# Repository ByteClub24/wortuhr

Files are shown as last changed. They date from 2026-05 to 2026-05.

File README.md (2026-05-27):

# Wortuhr

Open-Source-Wortuhr mit 10×10 LED-Raster — ein offenes Vereinsprojekt des [ByteClub](https://byteclub.at).

> Status: 🚧 in Entwicklung. CAD-Konstruktion läuft, Firmware folgt.

## Was ist das?

Eine Wortuhr zeigt die Uhrzeit in geschriebenen Worten an — bei dieser Variante mit österreichischen Dialekt-Begriffen wie *"HOIBE"*, *"OCHT"*, *"ZWO"*. Hinter einer Frontplatte sitzt ein 10×10-Raster aus einzeln ansteuerbaren NeoPixel-LEDs. Die richtigen Buchstaben werden zur passenden Uhrzeit beleuchtet, der Rest bleibt dunkel.

Die oberste Reihe ist für Icons reserviert (z.B. Müllerinnerung, Stammtisch-Hinweis), die unteren 9 Reihen zeigen die Zeit.

## Technische Eckdaten

- **LEDs:** Adafruit NeoPixel Strip, 60 LEDs/m, Pitch 16,7mm
- **Raster:** 10×10 = 100 LEDs
- **Controller:** ESP32 (Adafruit Feather V2 oder ESP32-S3), WLAN-Zeitabgleich via NTP
- **Helligkeitssensor:** LDR für automatische Nachtdimmung
- **Stromversorgung:** USB-C (5V/3A), optional Slimline-Powerbank
- **Außenmaße:** 195 × 195 × ca. 52 mm
- **Druck:** Bambu Lab X2D, 0,4mm Düse, 0,2mm Layer Height

## Aufbau (von vorne nach hinten)

1. **Frontplatte** (2mm, Galaxy-violett PLA) — Buchstaben als 0,2mm-Dünnstellen (Backlight-Technik)
2. **Diffusor** — weißes Pauspapier (0,4mm Spalt)
3. **Lichtgitter** (15mm, weißes PLA — matt oder glänzend, Hauptsache weiß für die Reflexion) — trennt jede LED-Zelle
4. **LED-Trägerplatte** (2mm, schwarz PLA) — mit Strip-Rillen und Lötkanälen
5. **Elektronikraum** (30mm) — ESP32 + optional Powerbank
6. **Rückwand** (2mm) — mit USB-C-Cutout, verschraubt mit Heat-Set M3 Inserts

Details siehe [`docs/aufbau.md`](docs/aufbau.md).

## Druckdaten

| Teil | Filament | Druckzeit |
|---|---|---|
| Lichtgitter | 140 g | 3:30 h |
| Trägerplatte | 60g | 1:30 h |

## Stückliste

Komplette BOM unter [`docs/stueckliste.md`](docs/stueckliste.md).

## Nachbauen

Anleitung folgt, sobald CAD und Firmware fertig sind. Die Konstruktion ist vollständig parametrisch — wer einen anderen LED-Pitch oder eine andere Größe möchte, kann das in Fusion 360 über die User Parameters anpassen.

Variante mit Holzrahmen statt gedrucktem Rahmen ist explizit vorgesehen — siehe `docs/aufbau.md`.

## Verein

Ein offenes Projekt des [ByteClub](https://byteclub.at). Beiträge sind willkommen — Issues und Pull Requests gerne.

## Lizenz

- **Hardware, CAD-Dateien, Dokumentation:** [CC-BY-SA 4.0](LICENSE)
- **Firmware** (sobald da): [MIT](LICENSE-FIRMWARE)

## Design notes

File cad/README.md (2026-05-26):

# CAD

Fusion-360-Konstruktion der Wortuhr.

## Dateien

- `wortuhr.f3d` — Hauptdatei (kommt sobald exportiert)
- `wortuhr_parameters.csv` — alle User Parameters als CSV, importierbar in Fusion über Parameter ändern → Importieren

## Konstruktionsprinzip

Vollständig parametrisch über User Parameters. Die wichtigsten Eingangsparameter:

| Parameter | Wert | Bedeutung |
|---|---|---|
| `ledPitch` | 16,6 mm | LED-Abstand |
| `gridCols`, `gridRows` | 10 | Raster |
| `frameWall` | 1,5 mm | Rahmenwand-Dicke |
| `wireMargin` | 10 mm | Verkabelungsrand |
| `gridHeight` | 15 mm | Lichtgitter-Höhe |
| `elecDepth` | 30 mm | Elektronikraum-Tiefe |

Außenmaß und Gesamttiefe ergeben sich automatisch aus diesen Parametern.

## Exports

Druckfertige STLs liegen in `exports/`.

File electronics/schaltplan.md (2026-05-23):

# Schaltplan

Detaillierte Beschreibung folgt.

## Übersicht

- **ESP32 Feather** als Controller, USB-C als Strom + Programmierung
- **NeoPixel Strip Data-In** an einem GPIO mit 470Ω-Schutzwiderstand
- **5V-Versorgung der LEDs** direkt vom USB-C (nicht über den ESP32)
- **GND gemeinsam** zwischen Controller und LEDs
- **LDR** mit 10kΩ-Pulldown an einem ADC-Pin, sitzt hinter einer 0,2mm-Aussparung in der Frontplatte

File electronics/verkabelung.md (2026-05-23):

# Verkabelung

## Strip-Layout (Boustrophedon)

Die 10 Strip-Reihen werden im Schlangenverlauf verbunden:

```
Reihe 1: → → → → → → → → → →  ┐
                              │
Reihe 2: ← ← ← ← ← ← ← ← ← ← ←┘
        ┌──────────────────────
        │
Reihe 3: → → → → → → → → → →  ┐
        ...
```

Die U-Turn-Brücken liegen abwechselnd rechts und links im Lötkanal der Trägerplatte. Pro Reihenwechsel werden drei Drähte gelötet: 5V, GND, DOUT → DIN.

Detail-Schema folgt mit Bild.

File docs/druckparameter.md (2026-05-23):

# Druckparameter

**Drucker:** Bambu Lab X2D
**Düse:** 0,4 mm
**Layer Height:** 0,2 mm (alle Maße sind Vielfache von 0,2mm konstruiert)

## Empfehlungen pro Bauteil

| Bauteil | Layer Height | Infill | Walls | Besonderes |
|---|---|---|---|---|
| Frontplatte | 0,2 mm | 100% | 3 | Die 0,2mm-Buchstabenrestwand ist 1 Layer. Druck mit guter Bett-Haftung und langsamer erste Schicht. |
| Lichtgitter | 0,2 mm | 100% | – | Filigran, langsamer drucken. Stege 1,2mm = 6 Layer dick. |
| LED-Trägerplatte | 0,2 mm | 20% | 3 | Schwarz, Rillen 0,4mm tief = 2 Layer |
| Rahmen | 0,2 mm | 20% | 4 | – |
| Rückwand | 0,2 mm | 20% | 3 | USB-C-Cutout muss sauber gedruckt sein |

## Filament-Tipps

- **Galaxy-violett für Front:** Vorher mit Backlight-Test prüfen, ob 0,2mm Restwand bei abgeschalteter LED noch ausreichend blickdicht ist (unbeleuchtete Buchstaben dürfen nicht sichtbar sein). Falls zu transluzent: 0,4mm Restwand (2 Layer) probieren oder auf Multi-Material wechseln.
- **Weiß matt für Gitter:** Wichtig für gute diffuse Reflexion. Glänzendes Weiß spiegelt zu hart.
- **Schwarz für Träger:** Verhindert Lichtleitung zwischen Zellen.

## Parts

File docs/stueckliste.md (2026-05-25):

# Stückliste (BOM)

## Elektronik

| Teil | Spec | Stück | Bezug |
|---|---|---|---|
| NeoPixel Strip | Adafruit, 60 LEDs/m, weiße PCB | ~1,7 m | Adafruit, Distrelec, Mouser |
| Mikrocontroller | Adafruit ESP32 Feather V2 oder ESP32-S3 Feather | 1 | Adafruit, Distrelec |
| Helligkeitssensor | LDR GL5528 | 1 | Reichelt, Conrad |
| Widerstand für LDR | 10 kΩ | 1 | Standardlager |
| Netzteil | 5V / 3A, USB-C | 1 | Reichelt |
| USB-C-Buchse (Panel-Mount) | optional, statt Feather-Buchse | 1 | – |

## Mechanik / Befestigung

| Teil | Spec | Stück | Bezug |
|---|---|---|---|
| Heat-Set Inserts | Ruthex M3 × 5,7mm | 4 | Amazon, Ruthex direkt |
| Schrauben | M3 × 8mm, Innensechskant (DIN 912) oder Senk (DIN 7991) | 4 | Standardlager |

## Filament (PLA)

| Teil | Farbe / Eigenschaft |
|---|---|
| Frontplatte | Galaxy-violett (dunkel, leicht transluzent) |
| Lichtgitter | weiß (matt oder glänzend, Hauptsache weiß für die Reflexion) |
| LED-Trägerplatte | schwarz |
| Rahmen | schwarz oder beliebig |
| Rückwand | schwarz |

## Sonstiges

| Teil | Spec |
|---|---|
| Pauspapier | weiß, transparent (Diffusor) |
| Sekundenkleber | für Magnetbefestigung (falls Variante mit Magneten) |
| Litze / Kupferlackdraht | für Strip-Lötbrücken (Boustrophedon-Verkabelung) |

## Optional

| Teil | Spec |
|---|---|
| Powerbank | Slimline 20000 mAh, Always-On-Modus (wichtig: viele Powerbanks schalten bei <80mA ab) |

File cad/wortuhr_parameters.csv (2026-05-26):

Name | Einheit | Ausdruck | Wert | Kommentare | Favorit
ledPitch | mm | 16.6 mm | 16.60 | Abstand der LEDs auf dem Stripe | false
gridWallThk | mm | 1.5 mm | 1.50 | Dicke der Gitterwände | false
rows |  | 10 | 10 | Anzahl der Reihen | false
cols |  | 10 | 10 | Anzahl der Spalten | false
gridXSize | mm | ( cols * ledPitch ) + gridWallThk | 167.50 | Breite des gesamten Gitters | false
gridYSize | mm | ( rows * ledPitch ) + gridWallThk | 167.50 | Höhe des gesamten Gitters | false
gridDepth | mm | 15 mm | 15.00 | Tiefe des Gritters | false
ledCutoutSize | mm | 9 mm | 9.00 | Seitenlänge des Quadratischen Cutouts für die LEDs auf dem Bank | false
solderCutoutSize | mm | 5 mm | 5.00 | Ausschnitte für das Löten der LED-Strips | false
carrierPlateThk | mm | 2 mm | 2.00 | LED Trägerplatten dicke | false
ledStripeWidth | mm | 5.5 mm | 5.50 | Breite des LED Strips für die Kleberinne | false
ledStripeHeight | mm | 0.4 mm | 0.40 | Höhe des LED Strips für die Kleberinne | false

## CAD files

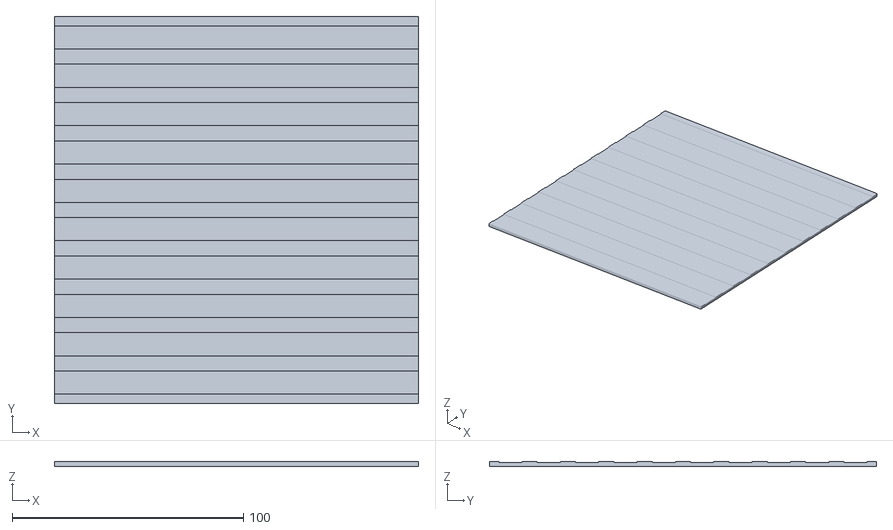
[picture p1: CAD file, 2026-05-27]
cad/exports/LedCarrier.stl
157.5 x 167.5 x 2.00

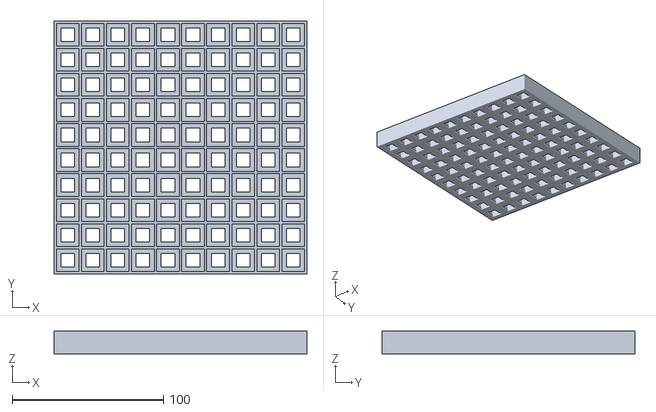
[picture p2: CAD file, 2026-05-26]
cad/exports/Grid.stl
167.5 x 167.5 x 15.0

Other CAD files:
cad/wortuhr.f3d

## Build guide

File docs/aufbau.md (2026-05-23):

# Aufbau

Detaillierte Beschreibung folgt.

## Schichtreihenfolge (von vorne)

1. Frontplatte
2. Pauspapier-Diffusor
3. Lichtgitter
4. LED-Trägerplatte
5. Elektronikraum
6. Rückwand

## Lichtweg

LED → eigene Gitterzelle (lichtdicht durch weiße Stege) → Pauspapier-Diffusor (streut Licht gleichmäßig) → 0,2mm-Buchstaben-Dünnstelle in der Frontplatte (Backlight-Technik)

## Holzrahmen-Variante

Der Aufbau funktioniert auch mit einem Holzrahmen statt des gedruckten Rahmens. Zu beachten:

- Innenmaß des Holzrahmens muss dem Außenmaß der gedruckten Innenteile entsprechen (Standard: 187×187mm Innenmaß bei 195×195mm gedrucktem Außenmaß)
- Innenseite des Holzrahmens schwarz beizen oder mit schwarzem Klebeband auskleiden, um Lichtaustritt zu vermeiden
- Anschlag für die Frontplatte: Vierkantleiste innen einkleben (z.B. 5×5mm), statt des gedruckten Falzes
- Befestigung der Rückwand: Holzschrauben oder Einschraubgewinde statt Heat-Set Inserts

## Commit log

2026-05-23 chore: initial repo structure
    [wortuhr.f3d, wortuhr_parameters.csv]
2026-05-23 led platte und claude md
    [wortuhr.f3d]
2026-05-25 grid konstruktion start
    [wortuhr.f3d, wortuhr_parameters.csv]
2026-05-25 grid und trägerplatte neue konstruktion
    [wortuhr.f3d]
2026-05-25 gitter export
    [Gitter.stl]
2026-05-26 Gitter optimiert
    [Gitter.stl, wortuhr.f3d, wortuhr_parameters.csv]
2026-05-27 Trägerplatte
    [LedCarrier.stl]
2026-05-27 carrier width change
    [Grid.stl, LedCarrier.stl, wortuhr.f3d]
